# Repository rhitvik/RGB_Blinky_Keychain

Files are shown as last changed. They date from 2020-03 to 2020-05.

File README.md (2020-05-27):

# RGB Blinky Keychain

<div align="center">

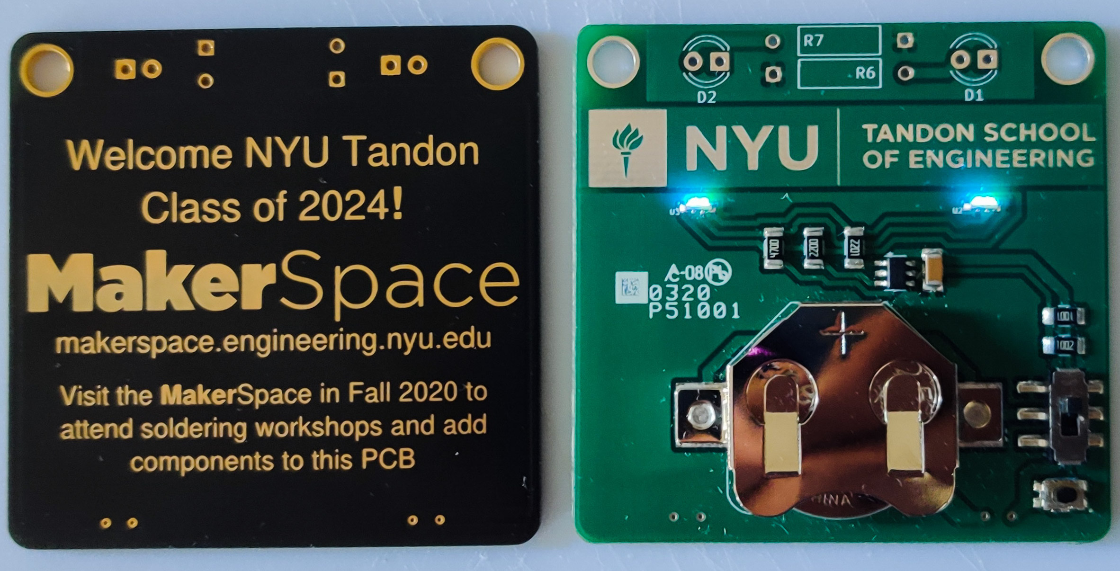
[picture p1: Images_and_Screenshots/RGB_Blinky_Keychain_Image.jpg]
RGB Blinky Keychain


<div align="left"> 

These are the blinky boards that NYU sent as the welcome gifts for the class of 2024. This RGB Blinky board features RGB breathing lights, PCB Art and doubles as a soldering practice kit. 1600 of these are manufactured in total. NYU is planning to have these boards manufactured for the class of 2025 and 2026 as well.

## Novelty of the Project
The novelty behind the project is the firmware developed for the microcontroller can generate an RGB breathing effect in a very limited space and resource-constrained ATtiny10 microcontroller. This microcontroller features 1 Kilobyte of flash memory and 32 bytes of RAM. While this microcontroller only supports only 2 PWM pins, I managed to implement a power-conscious, single-interrupt request process based HSV algorithm that worked as a State-Machine. 
Read more on Power-conscious breathing effect [here](https://www.instructables.com/id/How-to-Make-Proper-Rainbow-and-Random-Colors-With-/)

<div align="center"> 

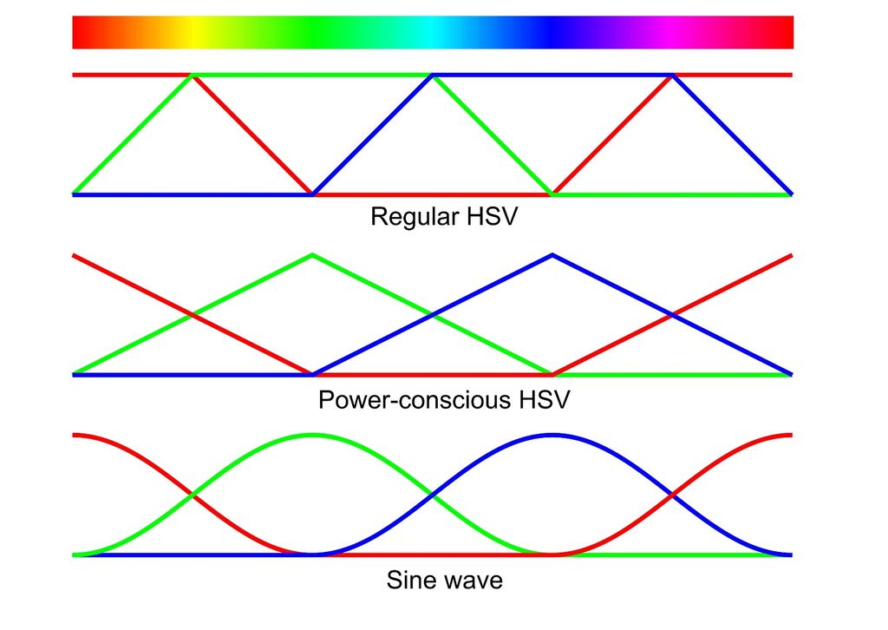
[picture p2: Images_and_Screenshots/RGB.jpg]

<div align="left"> 

## PCB Art
Monochromatic vector art is imported from any photo editing software like Adobe AI or Inkscape. This is the place where we also set the dimensions of the image we are looking to go with. We want to be sure that the bitmap extracted is negative or otherwise, the dimensions will be altered as the software only extracts the images that touch the bitmap on the extremities and not the dimensions set by us in the panel.
Once the image is exported as a jpeg, in the KiCad project file we go to the import bitmap file and calibrate the DPI labels to the values we set while exporting from the photo editing software. Again we select the negative plot while exporting the processed image as a KiCad file. This is because we obtained the inverted image in software and we will need to invert this again to obtain the positive mask profile. 

## Circuit
<div align="center"> 

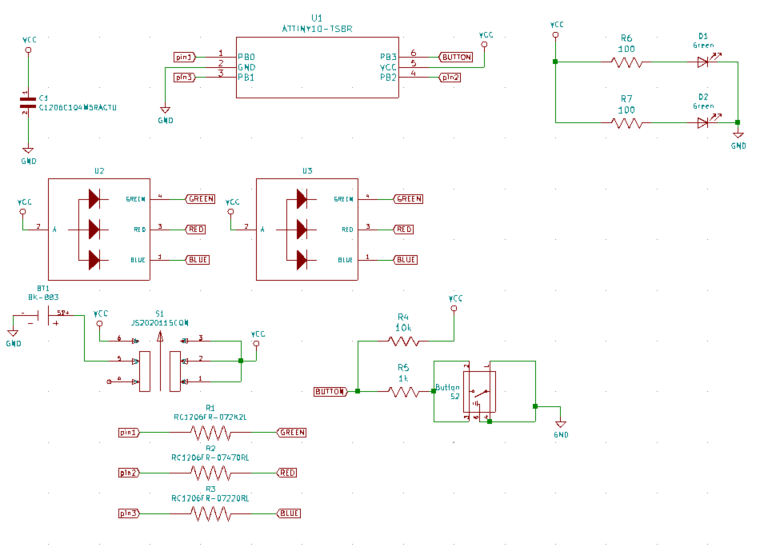
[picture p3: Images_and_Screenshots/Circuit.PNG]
Schematic Capture

<div align="left"> 

## Project files and Libraries
[LED Flasher Circuit](https://github.com/rhitvik/RGB_Blinky_Keychain/tree/master/Schematic_and_PCB)

## Link to Video
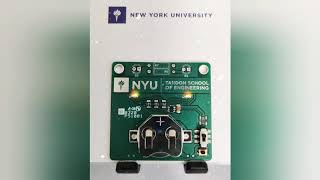
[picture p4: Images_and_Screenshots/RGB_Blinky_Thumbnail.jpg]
(https://www.youtube.com/watch?v=NwK5qySm0T8&feature=youtu.be)


## Bill Of Materials (BOM)
[Link to the BOM](https://github.com/rhitvik/RGB_Blinky_Keychain/tree/master/BOM)

## Firmware
[Click here to view Code](https://github.com/rhitvik/RGB_Blinky_Keychain/blob/master/Code/Project_Infineon_Rev-10/main.cpp)

**Note 1: USE FUSE SETTING 0xFE AFTER UPLOADING THE CODE (this disables the Reset pin and lets it be used as GPIO)**

**Note 2: SET THE FUSE SETTINGS ONLY AFTER THE CODE IS UPLOADED OR ELSE A HIGH VOLTAGE PROGRAMMER WILL BE REQUIRED**

**Programming/Debugging Unit Used: ATMEL ICE** [Shop Here](https://www.digikey.com/product-detail/en/microchip-technology/ATATMEL-ICE/ATATMEL-ICE-ND/4753379)

## Future Plans
RGB Blinky Keychain 2.0 is currently under development which includes upgraded LEDs that emit diffused light and are more power-efficient. Also, the boards will include a custom-designed High-Voltage TPI interface that will eliminate the microcontroller's requirement to be preprogrammed by the supplier and will bring the manufacturing costs lower. Also, these new boards will have multiple options for PCB Art to choose from.

A programming board is also under development for the aforementioned custom-designed TPI interface and this programming board will be able to program 10 Blinky Keychains simultaneously and alleviate the task of mass programming the developed boards.

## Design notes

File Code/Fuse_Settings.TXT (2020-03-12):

Project_Infineon_Rev-10 has the code for the project (atmel studio 7)

USE FUSE SETTING 0xFE AFTER UPLOADING THE CODE (this disables the reset pin and lets it to be used as GPIO)

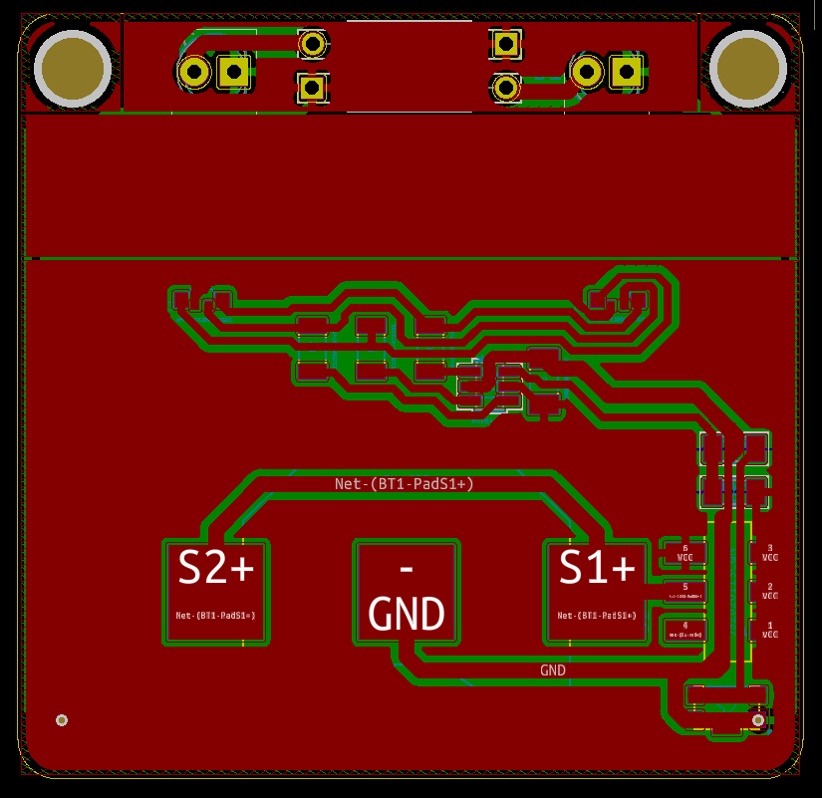
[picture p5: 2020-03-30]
Images_and_Screenshots/PCB_Design.PNG

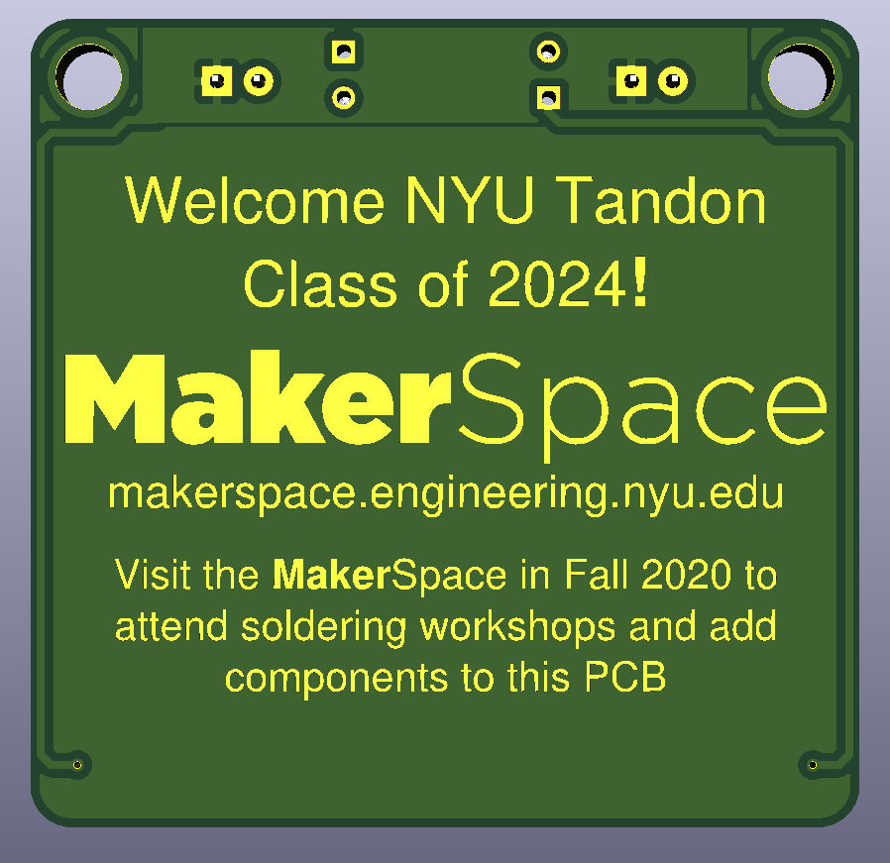
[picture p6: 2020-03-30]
Images_and_Screenshots/Screenshot_Back.PNG

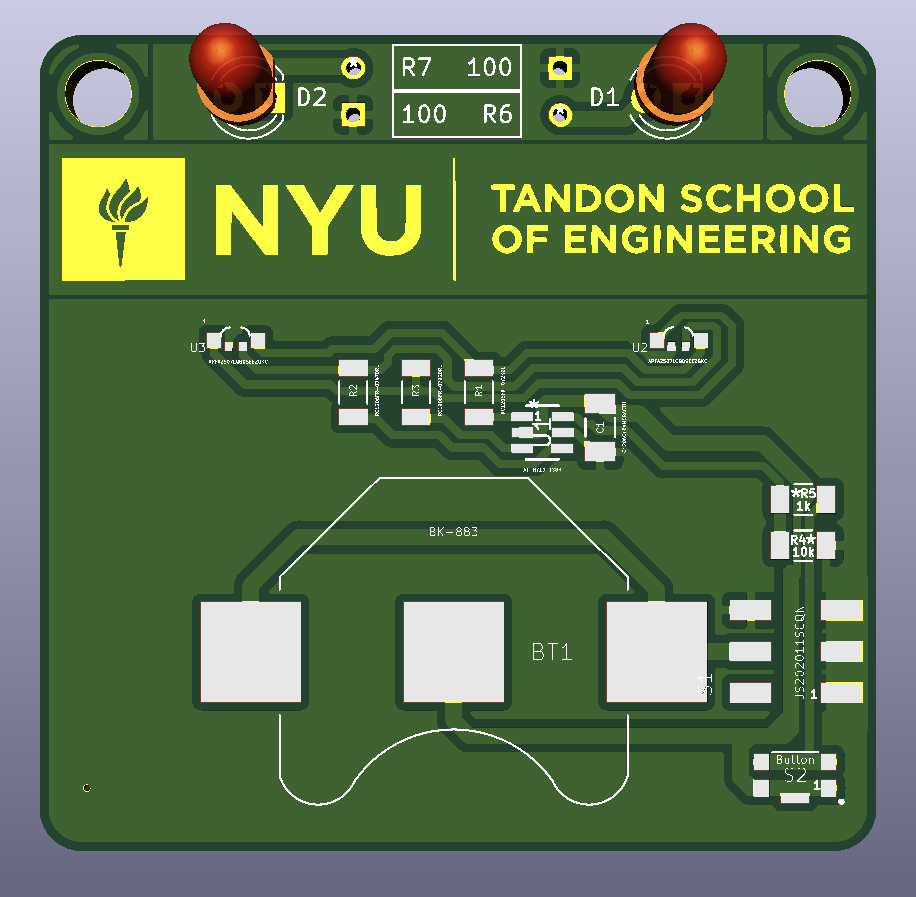
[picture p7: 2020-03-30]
Images_and_Screenshots/Screenshot_Front.PNG

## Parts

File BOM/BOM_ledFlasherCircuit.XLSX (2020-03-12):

Item | Quantity | Reference | Value | PART TYPE | PCB Footprint | Manufacturer Part Number | Manfacturer Name | Description | No Load / Do Not Install (DNI) | Link for Bulk | Link for Non-Bulk | Datasheet
1 | 2 | D1, D2 | XLUG12D | LED | LED_THT:LED_D4.0mm | XLUG12D | SunLED | LED GREEN DIFFUSED T-1 3/4 T/H | DNI | https://www.digikey.com/products/en?keywords=1497-1023-ND | https://www.digikey.com/products/en?keywords=1497-1023-ND | https://www.sunledusa.com/products/spec/XLUG12D.pdf
2 | 1 | BT1 | BK-883 | BATTERY RETAINER | BK-883:BAT_BK-883 | BK-883-TR | MPD (Memory Protection Devices) | BATTERY RETAINER COIN 20MM SMD |  | https://www.digikey.com/product-detail/en/mpd-memory-protection-devices/BK-883-TR/BK-883-TR-ND/755443 | https://www.digikey.com/product-detail/en/mpd-memory-protection-devices/BK-883-TR/BK-883-CT-ND/755450 | https://media.digikey.com/pdf/Data%20Sheets/Memory%20Protection%20PDFs/Coin_Cell_Guide.pdf
3 | 1 | C1 | 0.1µF ±20% 50V | CAP | C1206C104M5RACTU:CAPC3216X88N | C1206C104M5RACTU | KEMET | 0.1µF ±20% 50V Ceramic Capacitor X7R 1206 |  | https://www.digikey.com/product-detail/en/kemet/C1206C104M5RACTU/399-1248-2-ND/411247 | https://www.digikey.com/product-detail/en/kemet/C1206C104M5RACTU/399-1248-1-ND/411523 | https://content.kemet.com/datasheets/KEM_C1002_X7R_SMD.pdf
4 | 1 | R1 | 2.2K OHM | RES | 2K2:RC1206FR-072K2L | RC1206FR-072K2L | Yageo | RES SMD 2.2K OHM 1% 1/4W 1206 |  | https://www.digikey.com/product-detail/en/yageo/RC1206FR-072K2L/311-2.20KFRTR-ND/728624 | https://www.digikey.com/product-detail/en/yageo/RC1206FR-072K2L/311-2.20KFRCT-ND/731571 | https://www.yageo.com/upload/media/product/productsearch/datasheet/rchip/PYu-RC_Group_51_RoHS_L_10.pdf
5 | 1 | R2 | 470 OHM | RES | 470R:RC1206FR-07470RL | RC1206FR-07470RL | Yageo | RES SMD 470 OHM 1% 1/4W 1206 |  | https://www.digikey.com/product-detail/en/yageo/RC1206FR-07470RL/311-470FRTR-ND/728934 | https://www.digikey.com/product-detail/en/yageo/RC1206FR-07470RL/311-470FRCT-ND/731881 | https://www.yageo.com/upload/media/product/productsearch/datasheet/rchip/PYu-RC_Group_51_RoHS_L_10.pdf
6 | 1 | R3 | 220 OHM | RES | 220R:RC1206FR-07220RL | RC1206FR-07220RL | Yageo | RES SMD 220 OHM 1% 1/4W 1206 |  | https://www.digikey.com/product-detail/en/yageo/RC1206FR-07220RL/311-220FRTR-ND/728693 | https://www.digikey.com/product-detail/en/yageo/RC1206FR-07220RL/311-220FRCT-ND/731640 | https://www.yageo.com/upload/media/product/productsearch/datasheet/rchip/PYu-RC_Group_51_RoHS_L_10.pdf
7 | 1 | R4 | 10K OHM | RES | 10K:RC1206FR-0710KL | RC1206FR-0710KL | Yageo | RES SMD 10K OHM 1% 1/4W 1206 |  | https://www.digikey.com/product-detail/en/yageo/RC1206FR-0710KL/311-10.0KFRTR-ND/728483 | https://www.digikey.com/product-detail/en/yageo/RC1206FR-0710KL/311-10.0KFRCT-ND/731430 | https://www.yageo.com/upload/media/product/productsearch/datasheet/rchip/PYu-RC_Group_51_RoHS_L_10.pdf
8 | 1 | R5 | 1K OHM | RES | 1K:RC1206FR-071KL | RC1206FR-071KL | Yageo | RES SMD 1K OHM 1% 1/4W 1206 |  | https://www.digikey.com/product-detail/en/yageo/RC1206FR-071KL/311-1.00KFRTR-ND/728387 | https://www.digikey.com/product-detail/en/yageo/RC1206FR-071KL/311-1.00KFRCT-ND/731334 | https://www.yageo.com/upload/media/product/productsearch/datasheet/rchip/PYu-RC_Group_51_RoHS_L_10.pdf
9 | 2 | R6, R7 | 100 OHM | RES | Resistor100NYUpcb:SFR2500001000FR500 | SFR2500001000FR500 | Vishay BC Components | RES 100 OHM 0.4W 1% AXIAL | DNI | https://www.digikey.com/product-detail/en/vishay-bc-components/SFR2500001000FR500/PPC100YTR-ND/595639 | https://www.digikey.com/product-detail/en/vishay-bc-components/SFR2500001000FR500/PPC100YCT-ND/596845 | http://www.vishay.com/docs/28722/sfr16s25.pdf
10 | 1 | S1 | JS202011SCQN | SWITCH SLIDE DPDT | KMR421GULCLFS:SW_KMR421GULCLFS | JS202011SCQN | C&K | SWITCH SLIDE DPDT 300MA 6V |  | https://www.digikey.com/product-detail/en/c-k/JS202011SCQN/401-2002-2-ND/2094299 | https://www.digikey.com/product-detail/en/c-k/JS202011SCQN/401-2002-1-ND/1640098 | https://dznh3ojzb2azq.cloudfront.net/products/Slide/JS/documents/datasheet.pdf
11 | 1 | S2 | KMR421GULCLFS | SWITCH TACTILE SPST | JS202011SCQN:SW_JS202011SCQN | KMR421GULCLFS | C&K | SWITCH TACTILE SPST-NO 0.05A 32V |  | https://www.digikey.com/product-detail/en/c-k/KMR421GULCLFS/CKN12152TR-ND/9960945 | https://www.digikey.com/product-detail/en/c-k/KMR421GULCLFS/CKN12152CT-ND/3861094 | https://dznh3ojzb2azq.cloudfront.net/products/Tactile/KMR4/documents/datasheet.pdf
12 | 1 | U1 | ATTINY10-TS8R | IC MCU | ATtiny:ATTINY10-TS8R | ATTINY10-TS8R | Microchip Technology | IC MCU 8BIT 1KB FLASH SOT23 |  | https://www.digikey.com/product-detail/en/microchip-technology/ATTINY10-TSHR/ATTINY10-TSHRTR-ND/2051008 | https://www.digikey.com/product-detail/en/microchip-technology/ATTINY10-TSHR/ATTINY10-TSHRCT-ND/2136158 | http://ww1.microchip.com/downloads/en/DeviceDoc/Atmel-8127-AVR-8-bit-Microcontroller-ATtiny4-ATtiny5-ATtiny9-ATtiny10_Datasheet-Summary.pdf
13 | 2 | U2, U3 | APFA2507LQBDSEEZGKC | LED | APFA2507LQBDSEEZGKC:APFA2507LQBDSEEZGKC | APFA2507LQBDSEEZGKC | Kingbright | LED RGB CLEAR 4SMD R/A |  | https://www.digikey.com/product-detail/en/kingbright/APFA2507LQBDSEEZGKC/754-1970-2-ND/5803662 | https://www.digikey.com/product-detail/en/kingbright/APFA2507LQBDSEEZGKC/754-1970-1-ND/5803689 | http://www.kingbrightusa.com/images/catalog/SPEC/APFA2507LQBDSEEZGKC.pdf

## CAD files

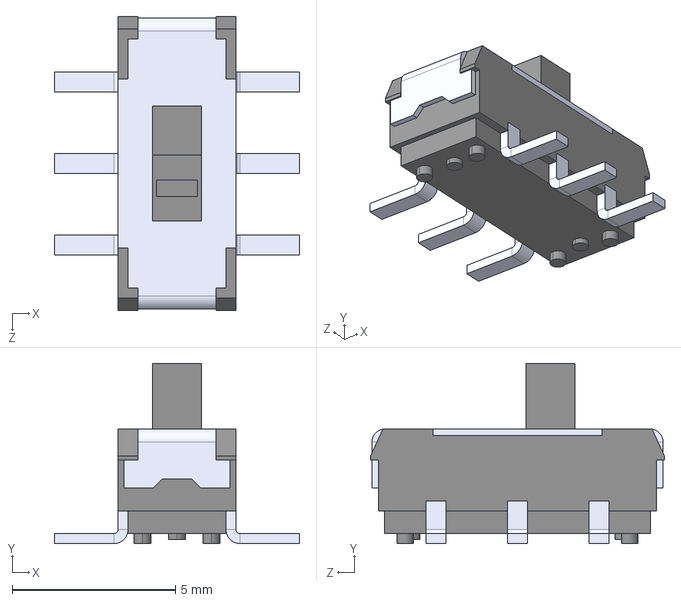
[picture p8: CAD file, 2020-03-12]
Schematic_and_PCB/Library_RGB_Blinky_Keychain/JS202011SCQN/JS202011SCQN--3DModel-STEP-56544.STEP
7.49 x 5.51 x 8.99 mm

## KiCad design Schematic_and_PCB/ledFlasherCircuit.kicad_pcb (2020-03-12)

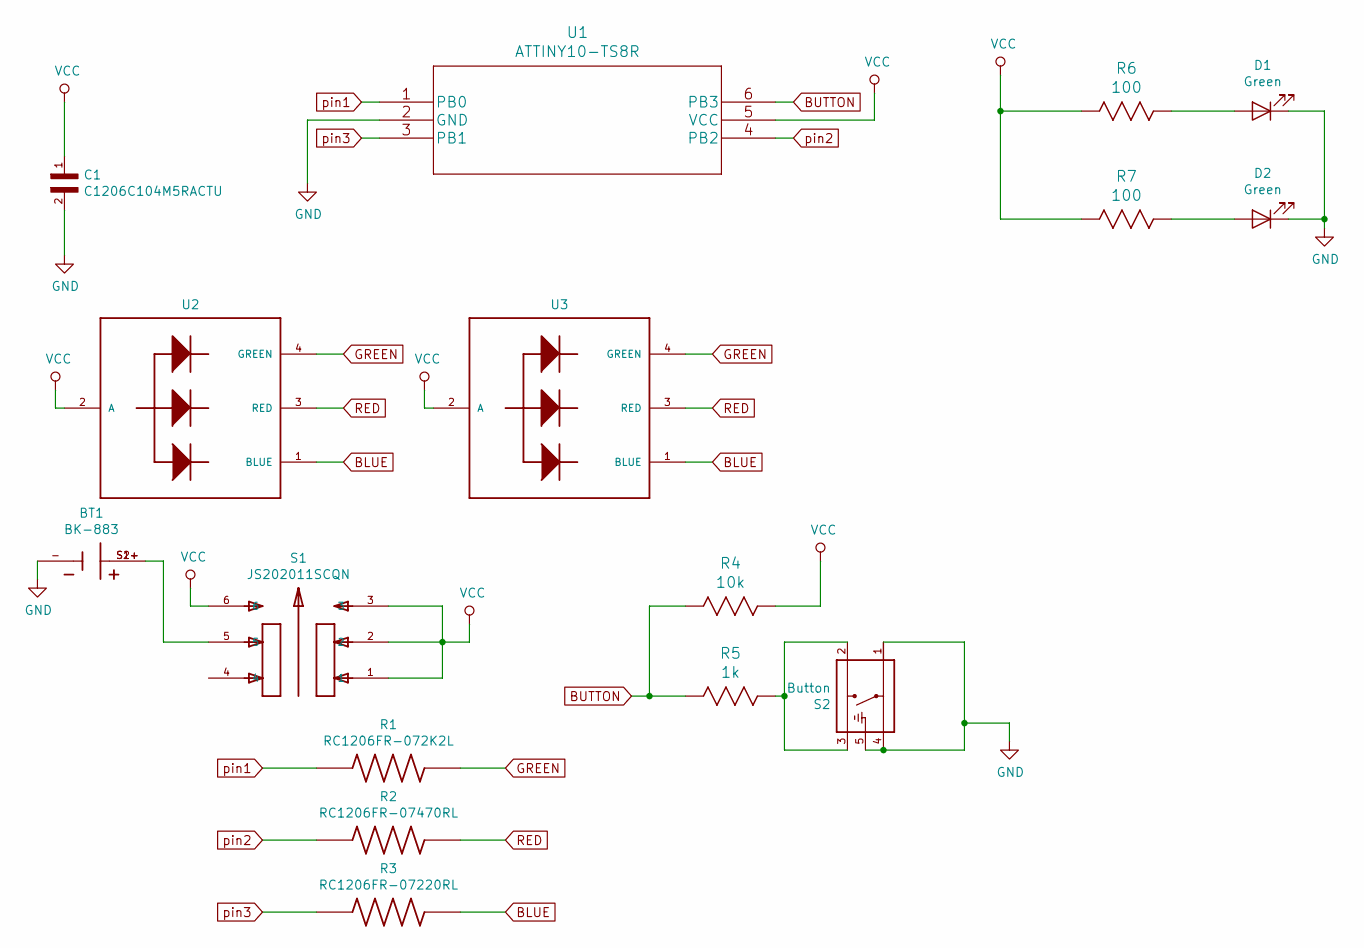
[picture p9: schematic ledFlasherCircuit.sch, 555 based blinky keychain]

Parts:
BT1: BK-883; BAT_BK-883
C1: C1206C104M5RACTU; CAPC3216X88N
D1, D2: Green; LED_D4.0mm
R1: RC1206FR-072K2L; RESC3116X65N
R2: RC1206FR-07470RL; RESC3116X65N
R3: RC1206FR-07220RL; RESC3116X65N
R4: 10k; RC1206FR-0710KL
R5: 1k; RC1206FR-071KL
R6, R7: 100; SFR2500001000FR500
S1: JS202011SCQN; SW_JS202011SCQN
S2: Button; SW_KMR421GULCLFS
U1: ATTINY10-TS8R
U2, U3: APFA2507LQBDSEEZGKC

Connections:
BLUE: R3.2, U2.1 (BLUE), U3.1 (BLUE)
BUTTON: R4.2, R5.1, U1.6 (PB3)
GND: BT1.-, C1.2, D1.1 (K), D2.1 (K), S2.1, S2.4, S2.5 (G), U1.2 (GND)
GREEN: R1.2, U2.4 (GREEN), U3.4 (GREEN)
unnamed: BT1.S1+ (+), BT1.S2+ (+), S1.5
unnamed: D1.2 (A), R6.2
unnamed: D2.2 (A), R7.2
unnamed: R5.2, S2.2, S2.3
RED: R2.2, U2.3 (RED), U3.3 (RED)
VCC: C1.1, R4.1, R6.1, R7.1, S1.1, S1.2, S1.3, S1.6, U1.5 (VCC), U2.2 (A), U3.2 (A)
pin1: R1.1, U1.1 (PB0)
pin2: R2.1, U1.4 (PB2)
pin3: R3.1, U1.3 (PB1)

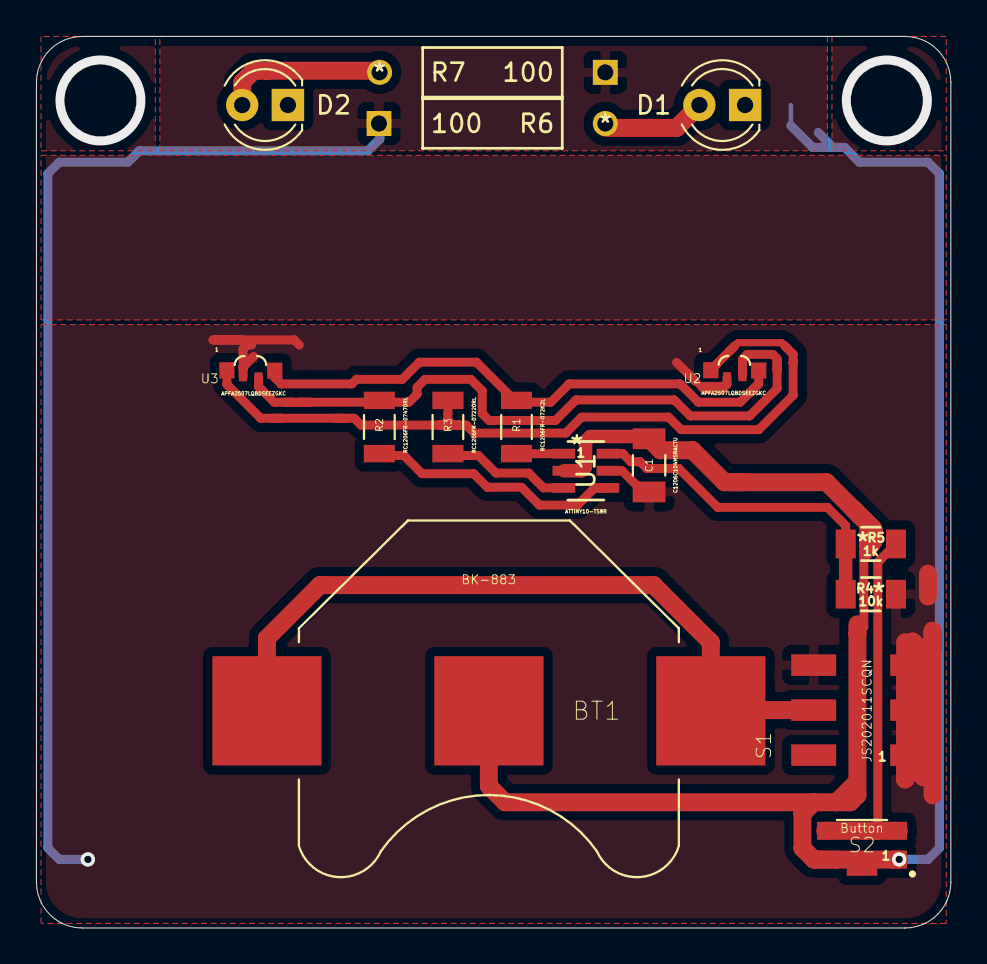
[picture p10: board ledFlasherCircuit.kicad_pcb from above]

Board: 2 copper layers, 50.8 x 49.5 mm, 16 parts (0 on the bottom side), 13 nets.

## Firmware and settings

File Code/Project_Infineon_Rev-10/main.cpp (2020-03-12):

/*
 * Project_Infineon_Rev-10.cpp
 *
 * Created: 12/26/2019 2:06:12 AM
 * Author : RHITVIK
 */ 
/*
 * Project_Infineon_Rev-9.cpp
 *
 * Created: 12/26/2019 1:01:46 AM
 * Author : RHITVIK
 */ 

/*
 * Project_Infeneon Rev-7.cpp
 *
 * Created: 11/30/2019 3:28:48 AM
 * Author : RHITVIK
 */ 

#define F_CPU	8000000UL
#define GREEN	0
#define RED		1
#define BLUE	2


#include <avr/io.h>
#include <util/delay.h>
#include <math.h>
#include <avr/interrupt.h>
#include <stdbool.h>

//		+====+
//	PB0 |*	 | PB3 (RESET)
//	GND |	 | VCC
//	PB1 |    | PB2
//		+====+

volatile uint8_t count[3] = {0,0,0};
volatile uint8_t Duty[3] = {0,100,0};
volatile bool increaseDuty[3] = {true,true,true};

volatile uint8_t MrCount = 0;
volatile uint8_t Theta = 0;
volatile uint8_t State = 1;

volatile uint8_t wait_white = 0;
volatile int count_white = 0;
volatile int Duty_white = 0;

volatile int MrCount_white = 0;
volatile bool increaseDuty_white = true;

int main(void)
{
	CCP = 0xD8;		// Unlock special consideration register
	CLKPSR = 0x00;	// Set the system clock to 8 MHz
	
	DDRB |= (1U<<PINB0) | (1U<<PINB1) | (1U<<PINB2);
	//DDRB &= ~(1U<<PINB3);
	PORTB |= (1U<<PINB0) | (1U<<PINB1) | (1U<<PINB2); //setting pins high will turnoff the RGB in common anode configuration
	//PUEB |= (1U<<PUEB3);	// Pull up on Pin B3
	
	TCCR0B |= (1U<<WGM02) | (1U<<CS00); 
	//Fast PWM mode with no Pre-Scalar Selection 
    TIMSK0 |= (1U<<OCIE0A);
	//Set Output Compare Interrupt Enable 
	
	// 8 000 000 / 10000 = 800
	OCR0AH = 800 >> 8;
	OCR0AL = 800 & 0xFF;
	
	sei();	// Enable Global Interrupts
	
	bool pressed = 0;
	bool interruptCleared = false;
	
	while (1){
		if (bit_is_clear(PINB,3))
		{
			if (pressed == 0)
			{
				pressed = 1;
				
				cli();
				interruptCleared = true;
				_delay_ms(30);			
				State = State + 1;
				State = (State >= 9)? 1:State;	
				
				count[GREEN] = 0;
				count[RED] = 0;
				count[BLUE] = 0;
				
				Duty[GREEN] = 0;
				Duty[RED] = (State == 1)? 100:0;
				Duty[BLUE] = 0;
				
				increaseDuty[GREEN] = true;
				increaseDuty[RED] = true;
				increaseDuty[BLUE] = true;

				MrCount = 0;
				Theta = 0;

				wait_white = 0;
				count_white = 0;
				Duty_white = 0;

				MrCount_white = 0;
 				increaseDuty_white = true;		
			}
		}
		else
		if(bit_is_set(PINB,3))
		{
			pressed = (pressed == 1)? 0:pressed;
			if (interruptCleared == true){
				interruptCleared = false;
				sei();
			}
		}					
    }	//while(1)
}	//int main()

ISR(TIM0_COMPA_vect){	// will be called 10,000 times every second
	//in 10000 hz we can work with a freq interval of 1000 hz
	// that is out of the 1000 times we can turn on the at a given count and ...
	// ... then turn off at a given interval
	// for example for a 50 percent duty cycle turn it on at the count of 500
	
	switch (State){
		case 1:
		///// case 1 starts here
		count[GREEN]++;
		count[RED]++;
		count[BLUE]++;
		
		MrCount++;
		if (MrCount == 255)
		{
			MrCount = 0;
			Theta++;
			Theta = (Theta > 90)? 0:Theta;
			
			switch(Theta){
				
				case 1 ... 30:
				increaseDuty[GREEN] = (increaseDuty[GREEN] == true)? increaseDuty[GREEN]:true;
				increaseDuty[RED] = (increaseDuty[RED] == false)? increaseDuty[RED]:false;
				
				Duty[GREEN] = (increaseDuty[GREEN] == true)? Duty[GREEN]+1: (Duty[GREEN] == 0)? 0:Duty[GREEN]-1;
				Duty[RED] = (increaseDuty[RED] == true)? Duty[RED]+1: (Duty[RED] == 0)? 0:Duty[RED]-1;
				Duty[BLUE] = (Duty[BLUE] == 0)? Duty[BLUE]:0;
				break;
				
				case 31 ... 60:
				increaseDuty[GREEN] = (increaseDuty[GREEN] == false)? increaseDuty[GREEN]:false;
				increaseDuty[BLUE] = (increaseDuty[BLUE] == true)? increaseDuty[BLUE]:true;
				
				Duty[GREEN] = (increaseDuty[GREEN] == true)? Duty[GREEN]+1: (Duty[GREEN] == 0)? 0:Duty[GREEN]-1;
				Duty[RED] = (Duty[RED] == 0)? Duty[RED]:0;
				Duty[BLUE] = (increaseDuty[BLUE] == true)? Duty[BLUE]+1: (Duty[BLUE] == 0)? 0:Duty[BLUE]-1;
				break;
				
				case 61 ... 90:
				increaseDuty[RED] = (increaseDuty[RED] == true)? increaseDuty[RED]:true;
				increaseDuty[BLUE] = (increaseDuty[BLUE] == false)? increaseDuty[BLUE]:false;
				
				Duty[GREEN] = (Duty[GREEN] == 0)? Duty[GREEN]:0;
				Duty[RED] = (increaseDuty[RED] == true)? Duty[RED]+1: (Duty[RED] == 0)? 0:Duty[RED]-1;
				Duty[BLUE] = (increaseDuty[BLUE] == true)? Duty[BLUE]+1: (Duty[BLUE] == 0)? 0:Duty[BLUE]-1;
				break;
			}			
		}
		
		switch (count[GREEN]){
			
			case 1 ... 99:
			if (count[GREEN] >= Duty[GREEN]){
				//turn off the pin
				PORTB |= 0x01;
			}
			break;
			
			case 100:
			count[GREEN] = 0; // set count back to 0
			//if the pin is off
			//turn
			if ( (bit_is_set(PINB,GREEN)) && (Duty[GREEN] != 0) ) {
				PORTB &= ~(1<<PINB0);
			}
			break;
			
		}
		
		switch (count[RED]){
			
			case 1 ... 99:
			if (count[RED] >= Duty[RED]){
				//turn off the pin
				PORTB |= 0x02;
			}
			break;
			
			case 100:
			count[RED] = 0; // set count back to 0
			//if the pin is off
			//turn
			if ( (bit_is_set(PINB,RED)) && (Duty[RED] != 0) ) {
				PORTB &= ~(1<<PINB1);
			}
			break;
		}
		switch (count[BLUE]){
			
			case 1 ... 99:
			if (count[BLUE] >= Duty[BLUE]){
				//turn off the pin
				PORTB |= 0x04;
			}
			break;
			
			case 100:
			count[BLUE] = 0; // set count back to 0
			//if the pin is off
			//turn
			if ( (bit_is_set(PINB,BLUE)) && (Duty[BLUE] != 0) ) {
				PORTB &= ~(1<<PINB2);
			}
			break;
			
		}
		///// case 1 ends here 
		break;
		
		case 2 ... 8:
		///// case 2 starts here
		count_white++;
		
		MrCount_white++;
		if (MrCount_white >= 255)
		{
			MrCount_white = 0;
			Duty_white = (increaseDuty_white == true)? Duty_white+1:Duty_white-1;
			
			if ((Duty_white > 30) || (Duty_white < 0)) {
				if (Duty_white > 30) { Duty_white = 30; increaseDuty_white = false;}
				else if (Duty_white < 0){
					Duty_white = 0;
					wait_white++;
					if (wait_white == 3){
						wait_white = 0;
						increaseDuty_white = true;
					}
				}
			}
			
		}
		
		switch (count_white){
			
			case 1 ... 99:
			if (count_white >= Duty_white){
				//turn off the pin
				PORTB |= 0x07;
			}
			break;
			
			case 100:
			count_white = 0; // set count back to 0
			//if the pin is off
			//turn
			if ( ((bit_is_set(PINB,0)) || (bit_is_set(PINB,1)) || (bit_is_set(PINB,2))) && (Duty_white != 0) ) {
				PORTB &= 0x06 + State;
			}
			break;
			
		}
		///// case 2 ends here
		break;

	} // switch (state)	
}

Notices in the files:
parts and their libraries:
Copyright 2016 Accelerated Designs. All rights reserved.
